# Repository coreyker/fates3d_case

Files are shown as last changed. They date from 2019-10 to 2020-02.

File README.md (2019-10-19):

# Fates 3d case

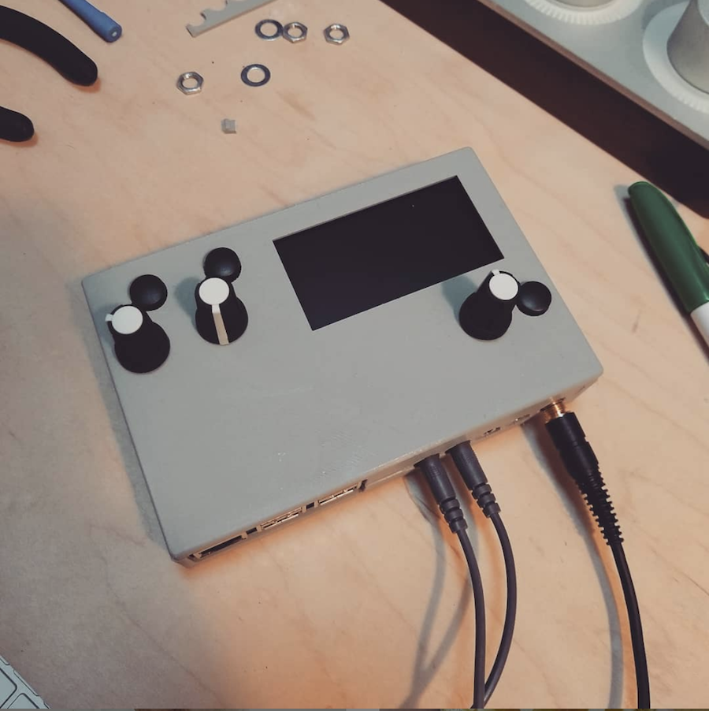
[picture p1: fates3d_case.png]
Fates3d


### What this is:

- This is a 3d printed case for "fates" designed in fusion 360
- It has built in standoffs and supports so you don't need to purchase any extra
- The case more or less snaps together

### What is missing:

- No consideration was given to cooling/air flow
- ~~There is no USB-C slot at the back of the case~~
- ~~There no hole for the 4th encoder~~
- (the above two items were added thanks to james everitt)

### Before you print this please know that:

- This is not perfect
- I'd recommend getting it printed by a friend with a 3d printer, or at a local hackerspace instead of spending a lot of money getting it printed using an online service 
- The tolerances are really tight. Once you install your Rpi + fates shield it will be a little difficult to remove. You might need a little spudger/pry tools to remove it

### Licence

- Creative Commons: Attribution-NonCommercial-ShareAlike 4.0 International
- In other words: you cannot sell this, and if you modify the design you cannot sell that either. Otherwise do whatever your heart desires

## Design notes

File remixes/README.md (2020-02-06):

## Add links to your forks below:

### James' Sturdy Case - https://github.com/JamesHagerman/fates3d_case

This case remix is held together with screws, nuts threaded onto the encoder shafts, and an internal bracket. It requires 17x 2.5m x 6mm threaded, hex head machine screws to fit together as well as 3 or 4 nuts for the encoder shafts depending on how many encoders you want to use. Test prints done in PLA on a Prusa i3 mk3s.

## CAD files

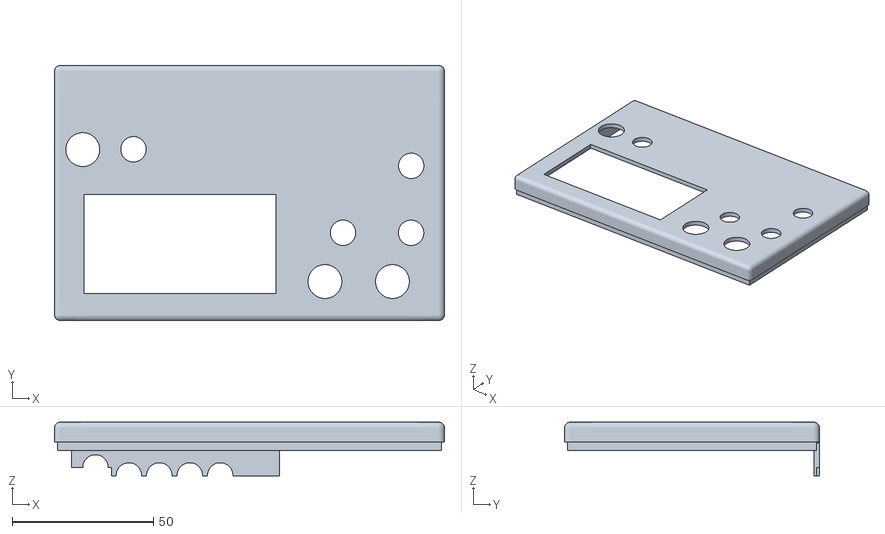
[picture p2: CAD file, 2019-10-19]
fates3d_case_top_4encoder.stl
138.0 x 90.2 x 19.0

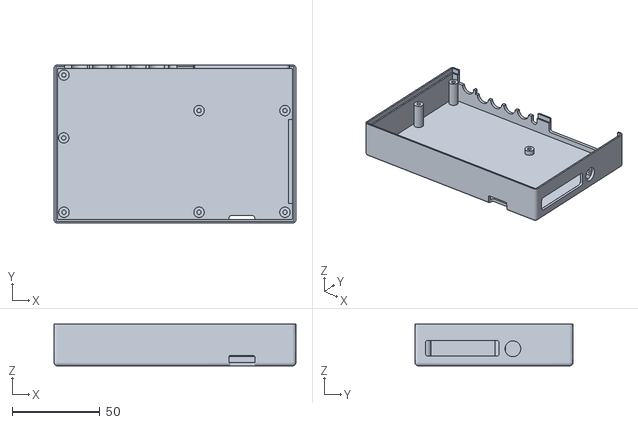
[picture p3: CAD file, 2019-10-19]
fates3d_case_bottom_USB.stl
138.0 x 90.2 x 23.8

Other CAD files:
fates3d_case_top_4encoder_USB.stl
fates3d_case_bottom.stl
fates3d_case_top.stl
fates3d_case.f3d

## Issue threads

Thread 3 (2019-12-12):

Some suggested design improvements

JamesHagerman, 2019-12-12:
I love this case!

I printed this on a Prusa i3 MK3S with PLA. For the most part, it fits really well! The top is friction fit only and my prints do not fit tightly enough to stay together well. It would be nice to have screw fasteners to hold the top of the case together.

While I had 2.5mm diameter hex screws, they were 6mm long and bottomed out in the RPi mounting holes. I drilled out the holes through the bottom of the case so they would still be snug against the RPi board. This worked well.

Some of the screw holes were also a little too big for the screws to bite well. I've had the same issue on my Fusion 360 designs and ended up always going with 2.4mm diameter holes as they seem to work well.

The display is also floating as I don't have any standoffs to go between the Fates board and the display. A 3D printed bracket to hold the screen would be a good addition.

The lack of cooling could be a real challenge. Even the RPi 3 was getting pretty warm after swapping out the RPi 4 because it was getting so hot.

Finally, the case slides around on the desk without rubber feet. Rubber feet stickers would work but the glue always seems to give up over the years. Instead, I'm planning on getting a neoprene rubber mouse pad, cutting it to size, and using rubber cement to attach it to the bottom of the case.

 I will try to make these changes if I find the time.

Thank you for sharing the Fusion 360 files!

JamesHagerman, 2020-01-28:
I've started working on some of these changes in PR https://github.com/coreyker/fates3d_case/pull/4. I have other changes done that still need to be tested.

Closed 2020-02-06.

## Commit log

2019-10-02 First commit. Currently does not have a USB-C slot for the rpi4, nor a hole for the fourth encoder
    [fates3d_case.f3d, fates3d_case_bottom.stl, fates3d_case_top.stl]
2019-10-04 Add files via upload
    Added the 4th encoder hole
    [fates3d_case_top_4encoder.stl]
2019-10-12 Added USB port on rear and 4th encoder
    [fates3d_case_bottom_USB.stl, fates3d_case_top_4encoder_USB.stl]
2020-02-06 Adding link to my more sturdy case remix.
